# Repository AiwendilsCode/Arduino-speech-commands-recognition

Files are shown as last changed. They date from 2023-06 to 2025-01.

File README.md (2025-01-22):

# Arduino speech commands recognition
Arduino speech commands recognition is project in which I tried teach Arduino Nano recognizing words or commands using neural network. This project is inspirated by another [speech commands recognition project by Peter Balch](https://www.instructables.com/Speech-Recognition-With-an-Arduino-Nano/).
Difference between mine and Balch's project is that I used different algorithm for recognizing words.

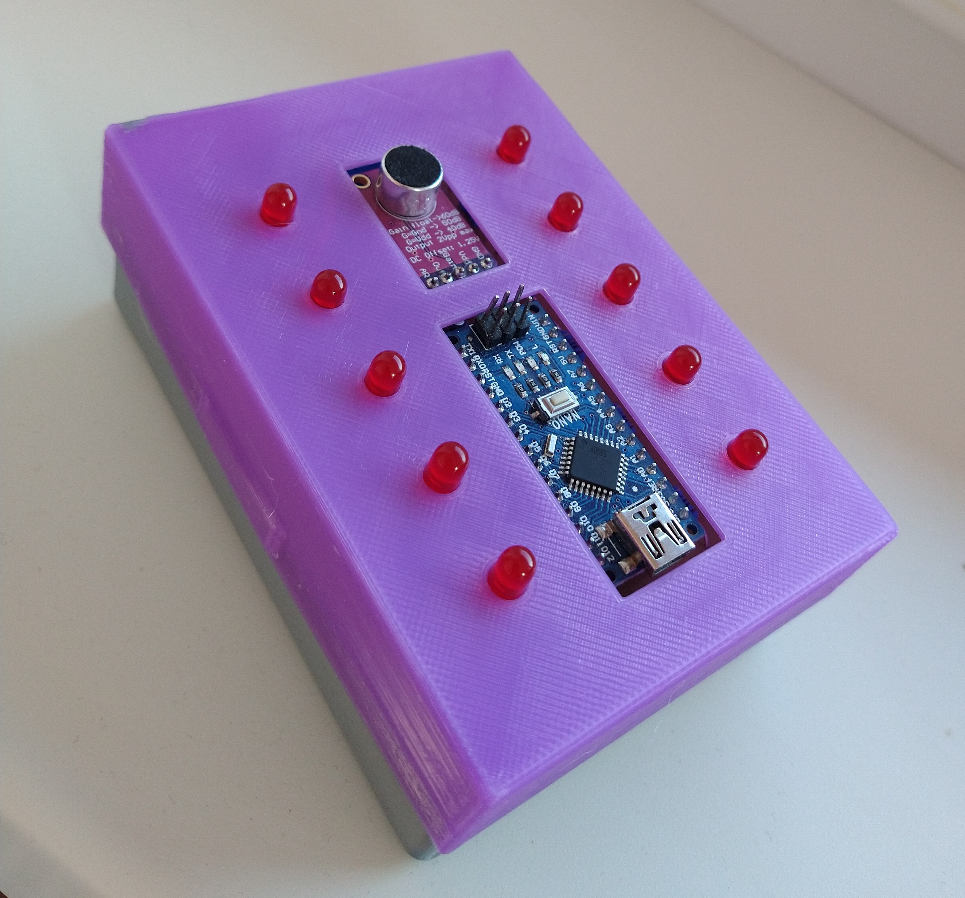
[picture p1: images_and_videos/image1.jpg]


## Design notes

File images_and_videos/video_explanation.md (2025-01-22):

[Showcase](showcase.mov) video contains demonstration of a final product. The demonatration consists of mew saying wake word 'hey nano' (leds are turned on in corners) and 4 effects in slovak:

- sviet - everything should be ON
- dookola - two leds should go around as a snake
- nahodne - randomly turn ON one led at a time
- vypni sa - all leds should be turned off
- dazd - efect of a rain, on both sides there shuold be two leds representing droplet.

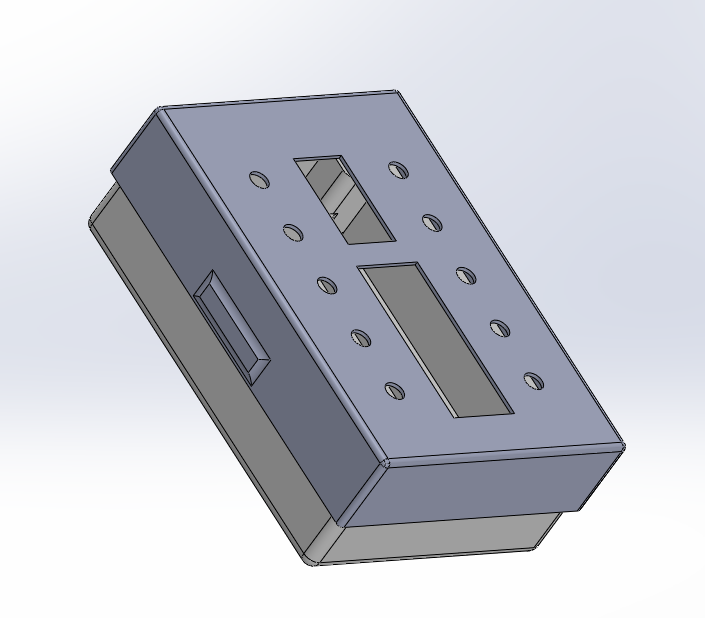
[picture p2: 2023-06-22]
hardware/Box/BoxComplete.png

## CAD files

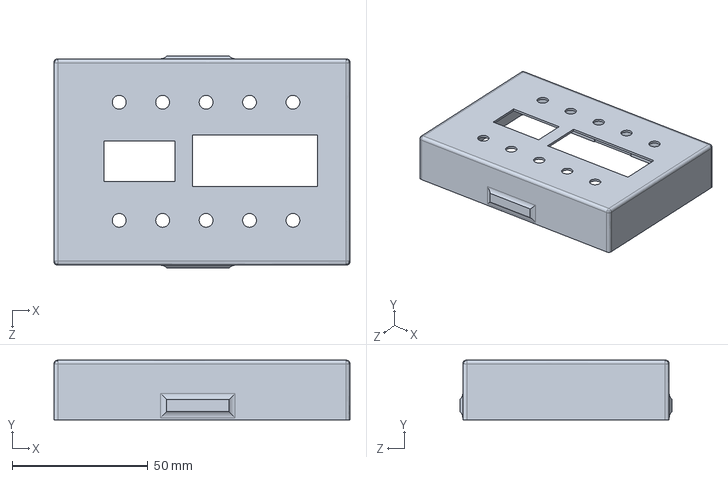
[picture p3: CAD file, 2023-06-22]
hardware/Box/boxUpperPart.SLDPRT
109.0 x 22.0 x 78.0 mm

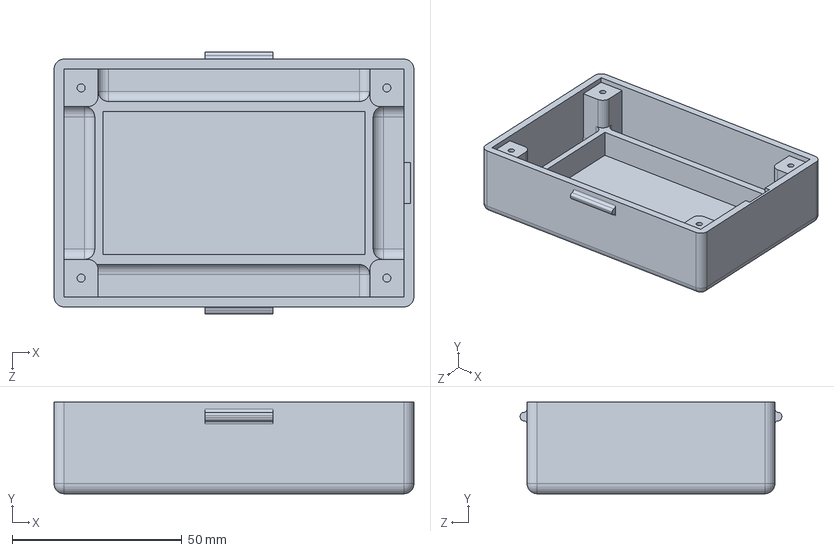
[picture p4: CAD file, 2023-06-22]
hardware/Box/boxDownPart.SLDPRT
106.0 x 27.0 x 77.0 mm

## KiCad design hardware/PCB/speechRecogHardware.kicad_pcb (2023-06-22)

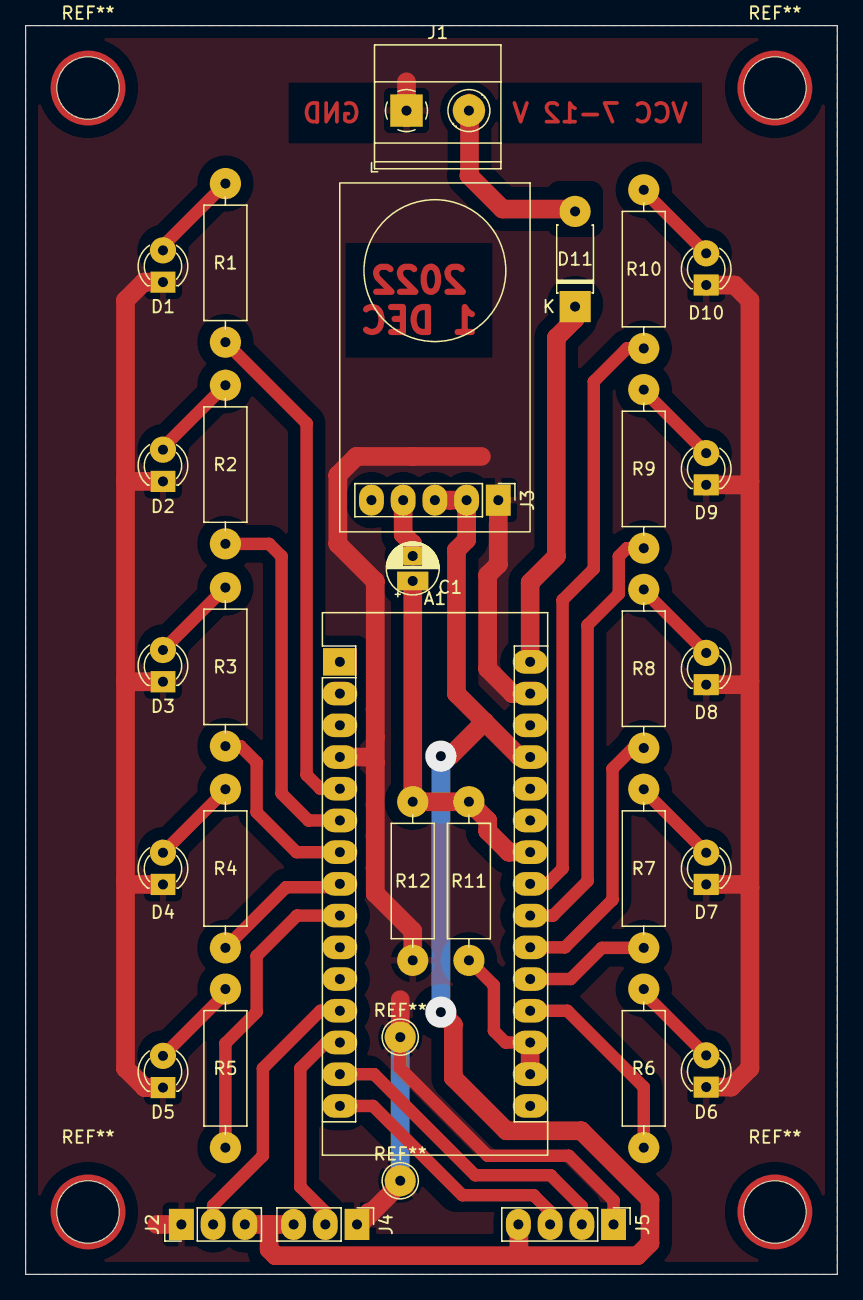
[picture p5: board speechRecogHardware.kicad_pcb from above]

Board: 2 copper layers, 65.0 x 100.0 mm, 30 parts (0 on the bottom side), 31 nets.

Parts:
A1: Arduino_Nano
C1: 1u; CP_Radial_D4.0mm_P2.00mm
D1, D2, D3, D4, D5, D6, D7, D8, D9, D10: LED; LED_D3.0mm
D11: DIODE; D_DO-41_SOD81_P7.62mm_Horizontal
J1: PWR 6-12V; TerminalBlock_Phoenix_MKDS-1,5-2_1x02_P5.00mm_Horizontal
J2: servo1; PinHeader_1x03_P2.54mm_Vertical
J3: MAX9814_Mic; PinHeader_1x05_P2.54mm_Vertical
J4: servo2; PinHeader_1x03_P2.54mm_Vertical
J5: HC04; PinHeader_1x04_P2.54mm_Vertical
R1, R2, R3, R4, R5, R6, R7, R8, R9, R10: 300R; R_Axial_DIN0309_L9.0mm_D3.2mm_P12.70mm_Horizontal
R11, R12: 47k; R_Axial_DIN0309_L9.0mm_D3.2mm_P12.70mm_Horizontal

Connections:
+3V3: A1.17 (3V3), A1.18 (AREF), R11.2
+5V: A1.27 (+5V), J2.3, J3.2, J3.3, J4.3, J5.4
/OUT: C1.2, J3.4
GND: A1.4 (GND), A1.29 (GND), D1.1 (K), D2.1 (K), D3.1 (K), D4.1 (K), D5.1 (K), D6.1 (K), D7.1 (K), D8.1 (K), D9.1 (K), D10.1 (K), J1.1, J2.1, J3.1, J4.1, J5.1, R12.2
MIC_IN: A1.24 (A5), C1.1, R11.1, R12.1
unnamed: A1.5 (D2), R1.2
unnamed: A1.6 (D3), R2.2
unnamed: A1.7 (D4), R3.2
unnamed: A1.8 (D5), R4.2
unnamed: A1.9 (D6), R5.2
unnamed: A1.19 (A0), R6.2
unnamed: A1.20 (A1), R7.2
unnamed: A1.21 (A2), R8.2
unnamed: A1.22 (A3), R9.2
unnamed: A1.23 (A4), R10.2
unnamed: D1.2 (A), R1.1
unnamed: D2.2 (A), R2.1
unnamed: D3.2 (A), R3.1
unnamed: D4.2 (A), R4.1
unnamed: D5.2 (A), R5.1
unnamed: D6.2 (A), R6.1
unnamed: D7.2 (A), R7.1
unnamed: D8.2 (A), R8.1
unnamed: D9.2 (A), R9.1
unnamed: D10.2 (A), R10.1
unnamed: D11.1 (A), J1.2
VIN: A1.30 (VIN), D11.2 (K)
echo: A1.15 (D12), J5.3
servo1: A1.12 (D9(PWM)), J2.2
servo2: A1.13 (D10(PWM)), J4.2
trigger: A1.14 (D11), J5.2

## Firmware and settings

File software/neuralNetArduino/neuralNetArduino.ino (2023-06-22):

#include <math.h>
#include <SPI.h>
#include <Arduino.h>

#include "hyperParams.h"
#include "linear.h"
#include "loadAudio.h"
#include "LEDeffects.h"
#include "timers.h"

/*
* 0 = hey nano
* 1 = random
* 2 = switching
* 3 = rain
* 4 = blinking
* 5 = loop
* 6 = turn off
* 7 = turn on
*/

int computed = 2;
Linear numberRecog = Linear(NUM_INPUT, NUM_HIDDEN, NUM_OUTPUT);
int currEffect = 6; // turn off

int prevComputed = 1;

float dummyInput[13][7] = {{20,34,50,66,57,36,26},
{26,28,43,52,52,30,17},
{20,24,34,50,38,19,9},
{31,24,39,57,58,40,37},
{19,27,43,47,45,31,24},
{10,25,40,39,31,19,9},
{4,12,17,24,28,17,11},
{0,7,11,10,7,4,3},
{0,1,2,4,3,2,2},
{0,1,1,1,2,2,2},
{0,1,1,1,2,2,2},
{0,1,1,1,2,2,2},
{0,1,2,1,2,2,2}
};

bool computeOutput()
{
  if (getInput(false))
  {
    computed = numberRecog.forward(CurBandData);
    return true;
  }
  return false;
}

void setup()
{
  Serial.begin(57600);
  Serial.println("reset");
  pinMode(AUDIO_IN, INPUT);
  analogReference(EXTERNAL);
  randomSeed(analogRead(AUDIO_IN)); // init audio capture and set random seed
  getInput(true);
  
  for (int i = 0; i < 2; i++)
  {
    for (int j = 0; j < NUM_LEDS; j++)
    {
      pinMode(leds[i][j], OUTPUT);
    }
  }

  numberRecog.forward(dummyInput);
  cli();
  interruptFunc = runEffect[EFFECT(currEffect)];
  sei();

  TIM1_enableOverflowInterrupt();
}

void loop()
{
  if (computeOutput())
  {
    if (computed == 0)
    {
      currEffect = computed;
      interruptFunc = runEffect[EFFECT(currEffect)];
    }
    else if (prevComputed == 0 && computed != 0)
    {
      Serial.println("effect detected");
      
      currEffect = computed;
      cli();
      interruptFunc = runEffect[EFFECT(currEffect)];
      sei();
    }
    Serial.println(computed);

    prevComputed = computed;
  }
  //runEffect[EFFECT(currEffect)]();
}

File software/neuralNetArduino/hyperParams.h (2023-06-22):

#ifndef HYPERPARAMS_H
#define HYPERPARAMS_H

#define NUM_SEGMENTS 13
#define NUM_BANDS	 7

#define pinA 2
#define pinB 3
#define pinC 4
#define pinD 5
#define pinE 6
#define pinF 7
#define pinG 8

#ifndef getBit
#define getBit(sfr, bit) (_SFR_BYTE(sfr) & _BV(bit))
#endif

#define NUM_OUTPUT 8
#define NUM_HIDDEN 30
#define NUM_INPUT  (NUM_SEGMENTS * NUM_BANDS)

#define NUM_LEDS 10

#define EFFECT(x) (x)

const int AUDIO_IN = A5;

const char SegmentSize = 50; //in mS
const char hyster = 2;
const char thresh = 100;

float CurBandData[NUM_SEGMENTS][NUM_BANDS];

#endif // !HYPERPARAMS_H

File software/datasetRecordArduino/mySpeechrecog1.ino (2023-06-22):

//-----------------------------------------------------------------------------
// Copyright 2021 Peter Balch
//   digital filter tester
//   subject to the GNU General Public License
//-----------------------------------------------------------------------------

#include <Arduino.h>
#include <SPI.h>
#include "myCoeffs.h"

//-----------------------------------------------------------------------------
// Defines, constants and Typedefs
//-----------------------------------------------------------------------------

// pins
const int AUDIO_IN = A5;

// get register bit - faster: doesn't turn it into 0/1
#ifndef getBit
#define getBit(sfr, bit) (_SFR_BYTE(sfr) & _BV(bit))
#endif

//-----------------------------------------------------------------------------
// Global Constants
//-----------------------------------------------------------------------------

const byte NumSegments = 13;
const byte SegmentSize = 50; //in mS
const byte hyster = 2;
const byte thresh = 100;

//-----------------------------------------------------------------------------
// Global Variables
//-----------------------------------------------------------------------------

word CurBandData[NumSegments][nBand + 1]; //current band data

//-------------------------------------------------------------------------
// GetSerial
//-------------------------------------------------------------------------
byte GetSerial() {
  while ( Serial.available() == 0 );
  return Serial.read();
}

//-------------------------------------------------------------------------
// PollBands
//-------------------------------------------------------------------------
bool PollBands(bool init)
{
  bool IsPos, Collecting;
  static unsigned long prevTime;
  byte band, seg, val1, val2;
  const byte hyster = 20;
  static int zero = 500;
  static byte curSegment = 255;
  long val;
  word zcr; // 
  static int valmax[10];
  static int pd[10] = {0, 0, 0, 0, 0, 0, 0, 0, 0, 0};
  static int ppd[10] = {0, 0, 0, 0, 0, 0, 0, 0, 0, 0};
  static int ppval = 0;
  static int pval = 0;

  if (init)
  {
    memset(pd, 0, sizeof(pd));
    memset(ppd, 0, sizeof(ppd));
    memset(CurBandData, 0, sizeof(CurBandData));
    pval =  0;
    ppval =  0;
    return false;
  }

  val = 0;
  IsPos = true;
  Collecting = false;

  for (curSegment = 0; curSegment < NumSegments; curSegment++) {
    zcr = 0;
    prevTime = 0;
    memset(valmax, 0, sizeof(valmax));

    prevTime = millis();
    while (millis() - prevTime < SegmentSize)
    {
      while (!getBit(ADCSRA, ADIF)) ; // wait for ADC
      val1 = ADCL; // ADCL must be read first
      val2 = ADCH;
      bitSet(ADCSRA, ADIF); // clear the flag
      bitSet(ADCSRA, ADSC); // start ADC conversion
      val = val1;
      val += val2 << 8;

      if (val < zero)
        zero--; else
        zero++;
      val = val - zero;

      if (!Collecting) {
        if (abs(val) > thresh)
          Collecting = true; else
          return false;
      }

      if (IsPos)
      {
        if (val < -hyster)
        {
          IsPos = false;
          zcr++;
        }
      } else {
        if (val > +hyster)
        {
          IsPos = true;
          zcr++;
        }
      }
      ppval = pval;
      pval = val;

      for (band = 0; band < nBand; band++) // namiesto fourier transform
      {
        int L1, L2;
        L1 =  ((-(filt_b1[band]) * pd[band] - filt_b2[band] * ppd[band]) >> 16) + val;
        L2 = (filt_a0[band] * L1 - filt_a0[band] * ppd[band]) >> 16;
        ppd[band] = pd[band];
        pd[band] = L1;
        if (abs(L2) > valmax[band])
          valmax[band]++;
      }
    }

    for (band = 0; band < nBand; band++)
      CurBandData[curSegment][band + 1] = valmax[band];
    CurBandData[curSegment][0] = zcr;
  }

  if (Collecting) {  
    PrintCurBandData();
    delay(500);
  }

  return Collecting;
}

//-----------------------------------------------------------------------------
// PrintCurBandData
//-----------------------------------------------------------------------------
void PrintCurBandData(void)
{
  byte seg, i, band, low, high;

  Serial.write("a");
  for (seg = 0; seg < NumSegments; seg++) {
    for (band = 0; band < nBand + 1; band++) {
      high = highByte(CurBandData[seg][band]);
      low = lowByte(CurBandData[seg][band]);
      Serial.write(high);
      Serial.write(low);
      Serial.write(" ");
    }
    Serial.write("\n");
  }
}

//-------------------------------------------------------------------------
// setup
//-------------------------------------------------------------------------
void setup(void)
{
  Serial.begin(57600);
  Serial.println("speechrecog");

  pinMode(AUDIO_IN, INPUT);
  analogReference(EXTERNAL);
  analogRead(AUDIO_IN); // initialise ADC to read audio input

  Serial.println("0 0 0 0 0 0 350");

  PollBands(true);
}

//-----------------------------------------------------------------------------
// Main routines
// loop
//-----------------------------------------------------------------------------
void loop(void)
{
  if (PollBands(false))
  PrintCurBandData();
}

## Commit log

2023-06-22 add hardware
    [boxDownPart.SLDPRT, boxUpperPart.SLDPRT, speechRecogHardware.kicad_pcb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]
2023-06-22 add arduino neural net
2023-06-22 add program for record dataset on arduino
2025-01-22 Add images and videos of final device.
